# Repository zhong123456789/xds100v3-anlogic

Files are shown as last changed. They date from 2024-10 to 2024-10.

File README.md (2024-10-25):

#  **`Anlogic EF2M45 XDS100V3国产化方案`**

XDS100V3的FPGA部分仅用作JTAG协议转换功能，因此可选择使用国产FPGA；目前选择Anlogic方案，EF2M45，EF2M45封装为LQFP48，且包含内部Flash，无需外挂外部Flash存储FPGA bit文件，且仅需要单相供电，可降低layout难度；  
因为封装偏小，需要裁剪原有的部分引脚，屏蔽部分功能，当前已完成测试，实物如下：  

  

## 1.1、电路原理图

#### 电源部分
FPGA和FT2232仅需要1.8V、3.3V和VTAG  
* 3.3V电源电路，如下：     
  

* 1.8V电源，由FT2232 内部的LDO产生，后级VTAG仅需要1.8V作为参考，功耗不大   
  

* VTAG电源，根据JTAG TVD信号的电平，输出同步电压，给FPGA BANK0供电，实现与不同电平电路的互联
BANK0 手册要求供电电压>1.5V，建议D4使用低电压降的二极管，保证VTAG>1.5V  
  

FPGA个BANK电压，BANK1-3供电电压为3.3V，BANK0为VTAG 

#### FPGA部分 BANK0、BANK1
* BANK0:   
DTS JTAG的所有信号，FPGA的JTAG Pin和XDS100V3的JTAG Pin复用，通过EF_PROG_EN_n和EF_JTAGEN信号切换功能；
* BANK1：   
  串口信号;  
  50M时钟信号（原版位100M，当前修改为50M，通过内部的PL锁定至100M）;  
  POR_RST：复位信号；   
  PWERGOOD： TVD功能信号，当VTAG > 3V3/2时输出高电平，代表供电正常；    
  

  

#### FPGA部分 BANK2、BANK3
* BANK2  
ADV_MODE_LED：LED状态信号；  
Alt_Func_n  : FT2232输出的Alt功能控制信号；  
Dtsa_byp_n  : FT2232与FPGA间互联信号；  
CTL_DIS     : FT2232与FPGA间互联信号；  
* BANK3  
FT2232与FPGA间互联的大部分信号  

  

#### FT2232电路
FT2232电路电路如下：  
  

#### 注意
EF_JTAGEN建议使用<= 1K电阻下拉，否则会导致FPGA工作异常；  
  

## 1.2、FPGA VHDL文件综合
Anlogic EF2M45 使用Anlogic TangDynasty（简称TD）软件开发，因此我们需要使用TD软件重新综合VHDL文件；  

### 1.2.1、TD软件安装
[Anlogic官方TD下载链接](https://www.anlogic.com/support/tools-downloads)，官网下载需要升级到对应的权限，需要发邮件给Anlogic说明需求等待回复；建议下载仅包含Release的包，其他描述的可能不支持EF2M45器件  

  

安装完成后复制license到安装目录即可使用；  

### 1.2.2、创建工程、添加VHDL文件
* 创建工程  
选择EF2M45LG48B器件  
  

* FPGA的JTAG作为普通IO  
  

* 选择添加HDL文件  
  

* 移除dtsa_a3p060.vhd文件  
不需要dtsa_a3p060.vhd文件，移除即可  
  

* 设置xds-anlogic.vhdl为顶层文件  
该文件调用了dtsa_a3p125，配置dtsa_a3p125某些未使用的port为默认值  
  

### 1.2.3、添加PLL IP核

因为工程需要PLL将50M时钟信号锁频到100M，所以需要添加PLL IP核    
* 按照下图配置IP对应参数  
  

* 确认参数后点击生成VHDL文件  
  

  

* 刷新检查VHDL文件语法，确认语法正常  
  

### 1.2.4、添加引脚约束ADC文件
添加ADC引脚约束文件，分配配置FPGA引脚  
  

文件内容如下：  
```BASH
# bank 0 
set_pin_assignment	{ io_dts_keeper_pin }	{ LOCATION = P3 ; IOSTANDARD = LVCMOS33; PULLTYPE = NONE    ; SLEWRATE = SLOW; DRIVESTRENGTH = 4; }
set_pin_assignment	{ io_dts_nsrst_pin }	{ LOCATION = P6 ; IOSTANDARD = LVCMOS33; PULLTYPE = PULLUP  ; SLEWRATE = SLOW; DRIVESTRENGTH = 4; }
set_pin_assignment	{ o_dts_ntrst_pin }	    { LOCATION = P7 ; IOSTANDARD = LVCMOS33; PULLTYPE = NONE    ; SLEWRATE = SLOW; DRIVESTRENGTH = 4; }
set_pin_assignment	{ o_dts_emu3_pin }	    { LOCATION = P9 ; IOSTANDARD = LVCMOS33; PULLTYPE = PULLUP  ; SLEWRATE = SLOW; DRIVESTRENGTH = 4; }
set_pin_assignment	{ i_dts_emu2_pin }	    { LOCATION = P10; IOSTANDARD = LVCMOS33; PULLTYPE = PULLUP  ; }
set_pin_assignment	{ o_dts_tck_pin }	    { LOCATION = P11; IOSTANDARD = LVCMOS33; PULLTYPE = NONE    ; SLEWRATE = FAST; DRIVESTRENGTH = 4; }
set_pin_assignment	{ i_dts_tdo_pin }	    { LOCATION = P12; IOSTANDARD = LVCMOS33; PULLTYPE = PULLUP  ;}
set_pin_assignment	{ o_dts_tdi_pin }	    { LOCATION = P13; IOSTANDARD = LVCMOS33; PULLTYPE = NONE    ; SLEWRATE = FAST; DRIVESTRENGTH = 4; }
set_pin_assignment	{ io_dts_tmsc_pin }	    { LOCATION = P14; IOSTANDARD = LVCMOS33; PULLTYPE = NONE    ; SLEWRATE = FAST; DRIVESTRENGTH = 4; }

#bank 1
set_pin_assignment	{ i_dts_tvd_pin }	    { LOCATION = P19; IOSTANDARD = LVCMOS33; PULLTYPE = PULLDOWN; }
set_pin_assignment	{ i_por_n_pin }	        { LOCATION = P21; IOSTANDARD = LVCMOS33; PULLTYPE = NONE    ; }
set_pin_assignment	{ i_clk_50m }	        { LOCATION = P22; IOSTANDARD = LVCMOS33; PULLTYPE = NONE    ;  }
set_pin_assignment	{ o_rxd_out }	        { LOCATION = P24; IOSTANDARD = LVCMOS33; PULLTYPE = NONE    ; SLEWRATE = FAST; DRIVESTRENGTH = 20; }
set_pin_assignment	{ i_txd_in }	        { LOCATION = P25; IOSTANDARD = LVCMOS33; PULLTYPE = PULLUP  ; }
set_pin_assignment	{ o_pll_clk_out }	    { LOCATION = P16; IOSTANDARD = LVCMOS33; PULLTYPE = NONE    ; SLEWRATE = FAST; DRIVESTRENGTH = 20; }

#bank 2
set_pin_assignment	{ o_adv_mode_led }	    { LOCATION = P26; IOSTANDARD = LVCMOS33; PULLTYPE = NONE    ; SLEWRATE = SLOW; DRIVESTRENGTH = 4; }
set_pin_assignment	{ i_alt_function_n }	{ LOCATION = P27; IOSTANDARD = LVCMOS33; PULLTYPE = PULLUP  ; }
set_pin_assignment	{ i_dtsa_byp_n }	    { LOCATION = P28; IOSTANDARD = LVCMOS33; PULLTYPE = PULLUP  ; }
set_pin_assignment	{ o_ctlr_tdis_pin }	    { LOCATION = P30; IOSTANDARD = LVCMOS33; PULLTYPE = NONE    ; SLEWRATE = SLOW; DRIVESTRENGTH = 2; }

#bank 3
set_pin_assignment	{ i_ctlr_pod_rls_pin }	{ LOCATION = P34; IOSTANDARD = LVCMOS33; PULLTYPE = PULLUP  ; }
set_pin_assignment	{ i_ctlr_emu1_pin }	    { LOCATION = P36; IOSTANDARD = LVCMOS33; PULLTYPE = PULLUP  ; }
set_pin_assignment	{ o_ctlr_tvd_pin }	    { LOCATION = P37; IOSTANDARD = LVCMOS33; PULLTYPE = NONE    ; SLEWRATE = FAST; DRIVESTRENGTH = 20; }
set_pin_assignment	{ o_clk_fail_pin }	    { LOCATION = P38; IOSTANDARD = LVCMOS33; PULLTYPE = NONE    ; SLEWRATE = FAST; DRIVESTRENGTH = 20; }

set_pin_assignment	{ i_ctlr_nsrst_pin }	{ LOCATION = P39; IOSTANDARD = LVCMOS33; PULLTYPE = PULLUP  ; }
set_pin_assignment	{ o_ctlr_rtck_pin }	    { LOCATION = P40; IOSTANDARD = LVCMOS33; PULLTYPE = NONE    ; SLEWRATE = FAST; DRIVESTRENGTH = 20; }
set_pin_assignment	{ i_ctlr_emu0_pin }	    { LOCATION = P41; IOSTANDARD = LVCMOS33; PULLTYPE = PULLUP  ; }
set_pin_assignment	{ i_ctlr_emu_en_pin }	{ LOCATION = P42; IOSTANDARD = LVCMOS33; PULLTYPE = PULLUP  ; }

set_pin_assignment	{ i_ctlr_ntrst_pin }	{ LOCATION = P43; IOSTANDARD = LVCMOS33; PULLTYPE = PULLUP  ; }

set_pin_assignment	{ i_ctlr_tms_pin }	    { LOCATION = P44; IOSTANDARD = LVCMOS33; PULLTYPE = PULLUP  ; }
set_pin_assignment	{ o_tdo_to_ctlr }	    { LOCATION = P45; IOSTANDARD = LVCMOS33; PULLTYPE = NONE    ; SLEWRATE = FAST; DRIVESTRENGTH = 20; }
set_pin_assignment	{ i_ctlr_tdi_pin }	    { LOCATION = P46; IOSTANDARD = LVCMOS33; PULLTYPE = PULLUP  ; }
set_pin_assignment	{ i_ctlr_tck_pin }	    { LOCATION = P47; IOSTANDARD = LVCMOS33; PULLTYPE = PULLUP  ; }
```
### 1.2.5、添加时序约束SDC文件
参考3.2.4、添加引脚约束ADC文件，SDC文件内容如下  
```BASH
# create_clock -add -name <string> -period <double> -waveform <string> target
# new input clock is 50 Mhz
create_clock  -period 20 -waveform {0 10} [get_ports i_clk_50m]
create_clock  -period 10 -waveform {0 5} [get_nets {pll_clk_u0/clkc_wire[0]}]

# fastest TCK can be is master_clk/2
create_generated_clock -name {internal_tck} -divide_by 2 -source [get_nets {pll_clk_u0/clkc_wire[0]}] [get_nets {dtsa_fpga/DTSK/TC0/tsm_pres_st[3]}]

#------------------------------------------------------
# False Path Constraints to test points and LEDs
#------------------------------------------------------

set_false_path -to [get_ports { o_adv_mode_led}]

#------------------------------------------------------
# False path to/from points with no real timing
#------------------------------------------------------

set_false_path -from [get_ports {io_dts_nsrst_pin}] -to [get_ports {o_clk_fail_pin}]
set_false_path -from [get_ports {i_ctlr_nsrst_pin}] -to [get_ports {io_dts_nsrst_pin} ]

set_false_path  -to [get_ports {o_ctlr_tvd_pin}]
set_false_path  -to [get_ports {o_ctlr_tdis_pin}]
set_false_path  -to [get_ports {o_clk_fail_pin}]

set_false_path -from [get_ports {i_ctlr_pod_rls_pin}] 
set_false_path -from [get_ports {i_dtsa_byp_n}] 
set_false_path -from [get_ports {i_ctlr_emu_en_pin}] 
set_false_path -from [get_ports {i_alt_function_n}]

set_false_path -from [get_ports {i_txd_in}]
set_false_path -to [get_ports {o_rxd_out}]

set_false_path -from [get_ports {i_dts_emu2_pin}]
set_false_path -to [get_ports {o_dts_emu3_pin}]
#------------------------------------------------------
# Maximum Delay Constraints
#------------------------------------------------------

set_max_delay 25.00 -from [get_ports {i_ctlr_ntrst_pin}] -to [get_ports {o_dts_ntrst_pin}]
```

### 1.2.6、综合VHDL文件
点击RUN按钮一键综合 HDL文件，可下方查看生产结构及资源消耗情况


### 1.2.7、烧录到FPGA FLASH
* 点击Download按钮,如果显示No hardware，可能是Anlogic USA JTAG下载器的驱动未安装需要手动安装，驱动目录位于 `软件安装目录/driver` 目录下  

* 安装完成驱动后，设备管理器，应该有`AL-Link` 设备  


* 将EF_JTAGEN信号拉高即可刷新出EF2M45B设备  


* 烧录到FPGA FLASH  



### 注意： ###   
因为FPGA的JTAG复用作为IO，但是与PCB上的丝印的映射不同，烧录下载时需要按下图连接下载器：  


## 1.3、FT2232 EEPROM设置
使用FTDI的官方软件[FT_Prog](https://ftdichip.com/utilities/)编辑配置FT2232，打开软件点击 `DEVICES` -> `Scan and Parse`，软件会自动扫描连接设备，按以下配置各参数：
* USB Device Descriptors:  


* USB Config Descriptors:  


* USB String Descriptors:  


* PortA Hardware Specific  


* PortA Driver  


* PortB Hardware Specific  


* PortB  Driver  


修改完成后点击 `DEVICES` -> `Program`烧录配置到FT2232外挂的EEPROM中，然后再点击软件`DEVICES` -> `Scan and Parse`刷新读取FT2232外挂的EEPROM信息：
* EEPROM信息如下


## 1.4、功能测试
使用TI 的CCS IDE测试XDS100V3，结果如下：   


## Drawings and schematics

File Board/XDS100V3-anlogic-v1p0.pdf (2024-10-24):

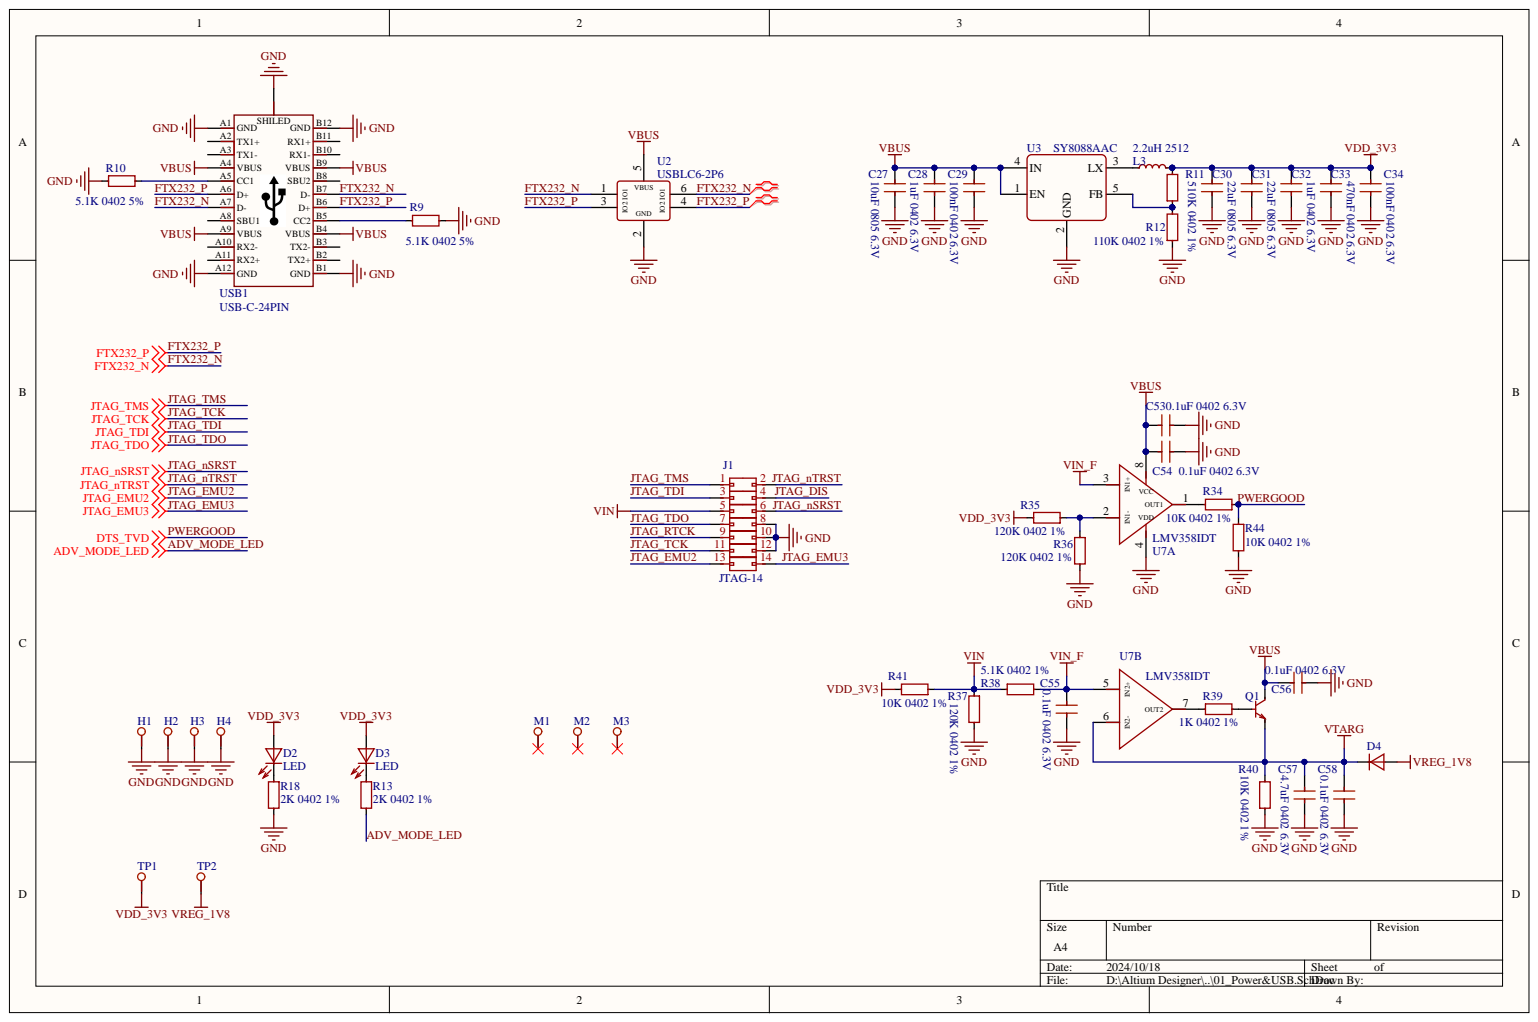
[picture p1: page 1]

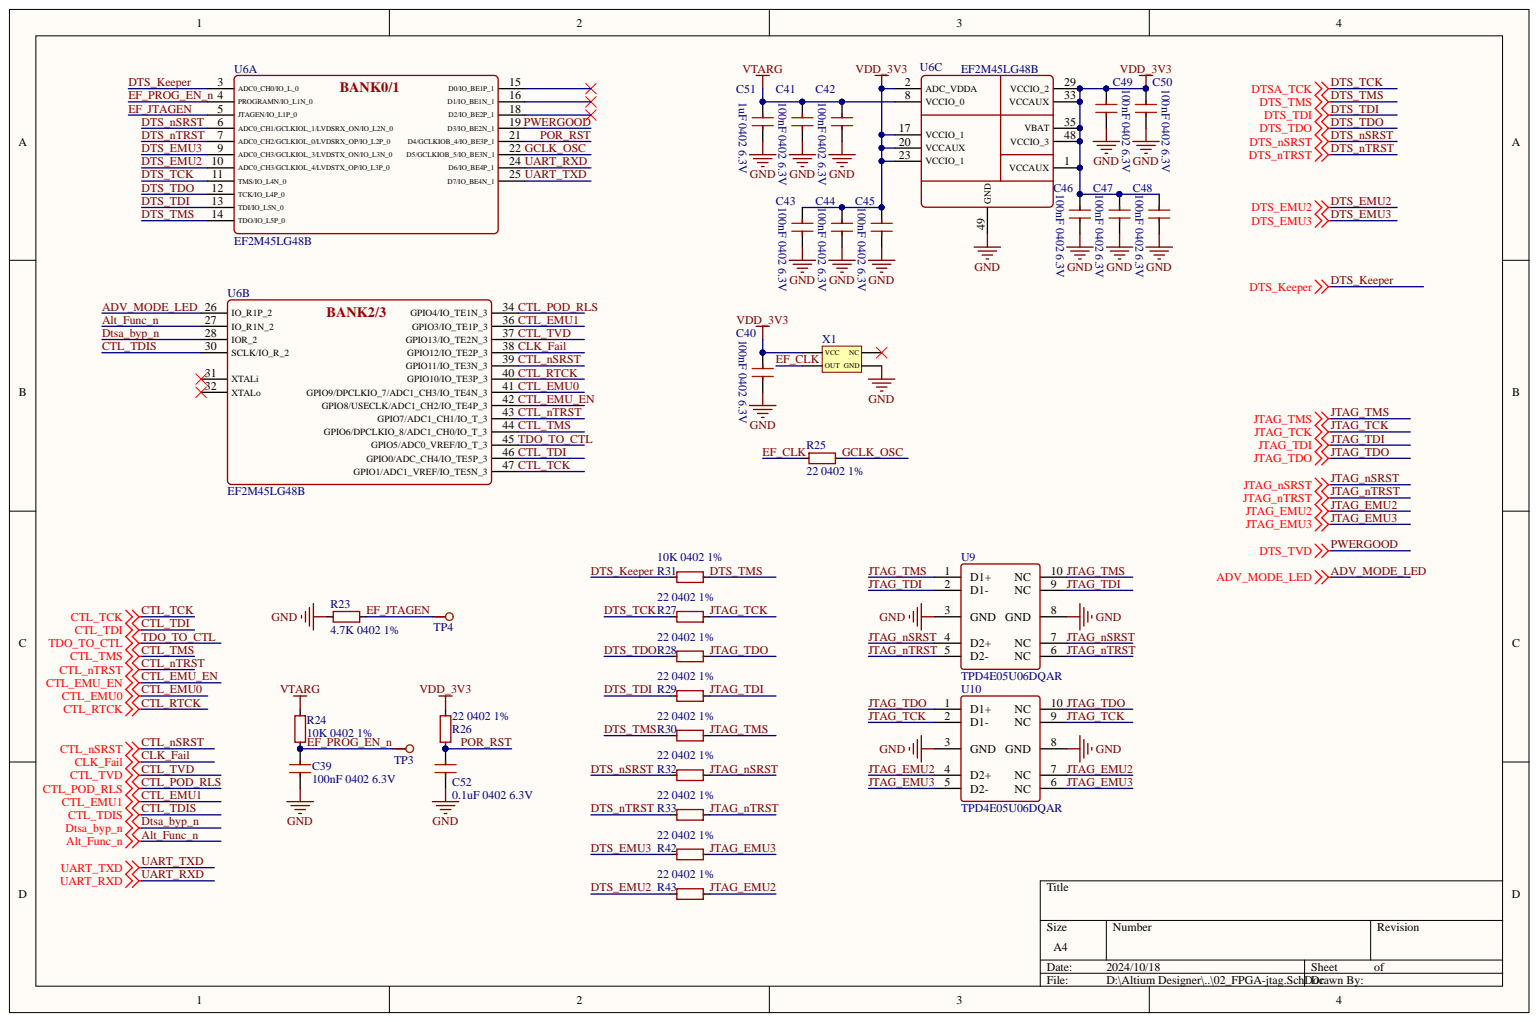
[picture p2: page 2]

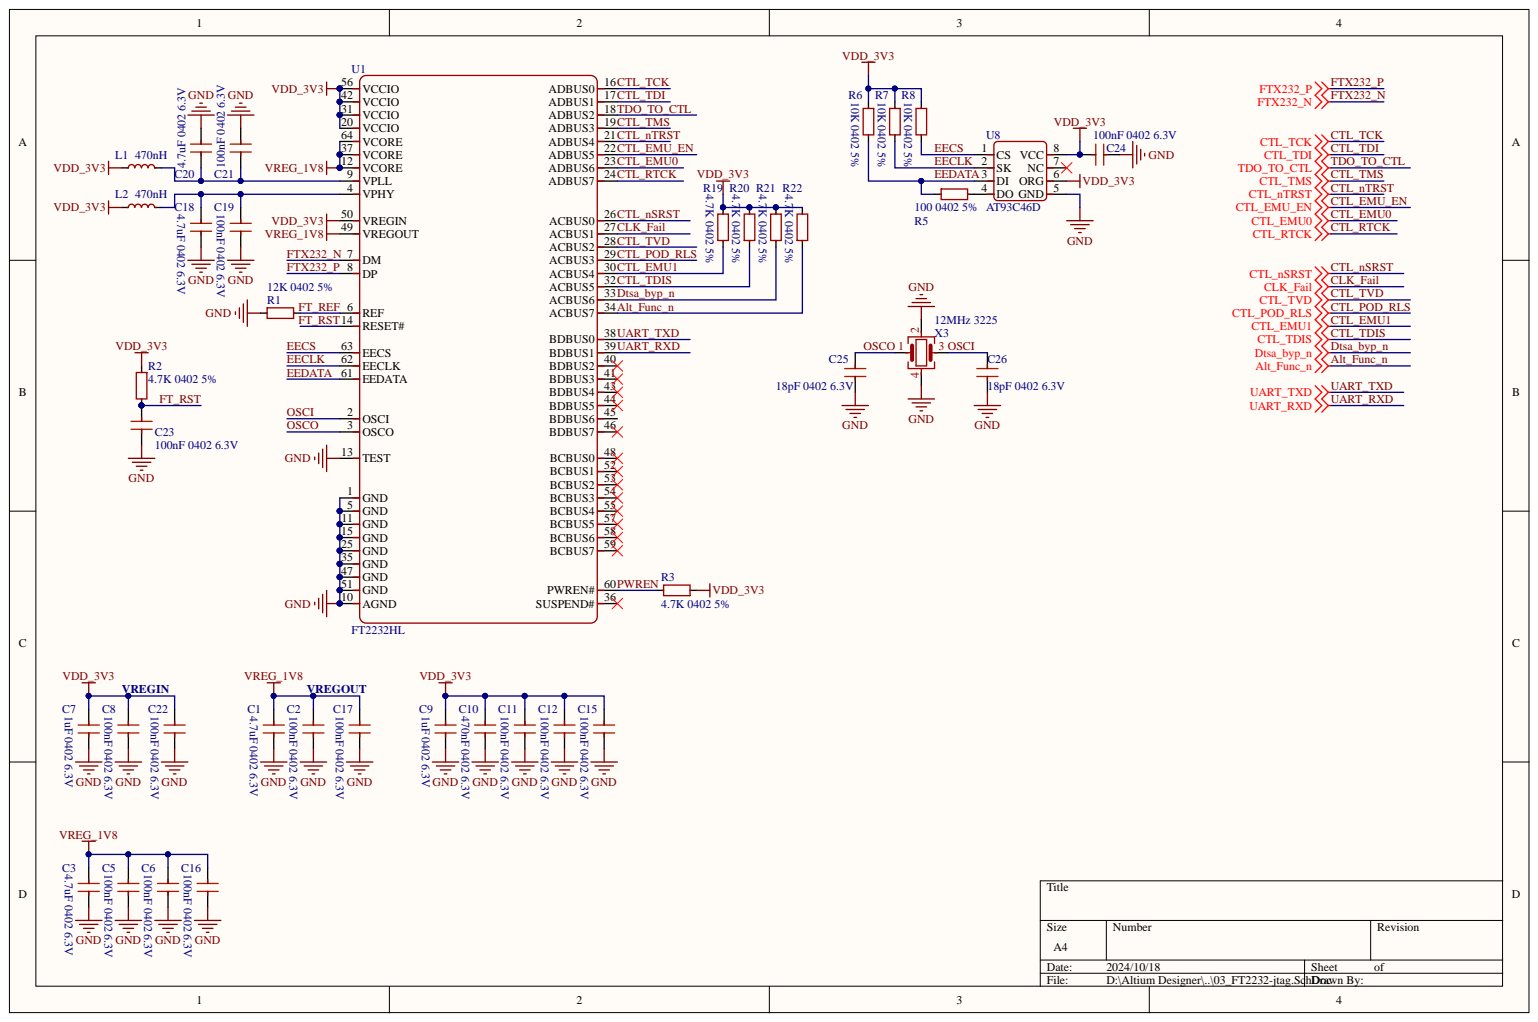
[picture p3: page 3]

VPHY 4 VPLL 9 VCORE 12 VCORE 37 VCORE 64 VCCIO 20 VCCIO 31 VCCIO 42 VCCIO 56

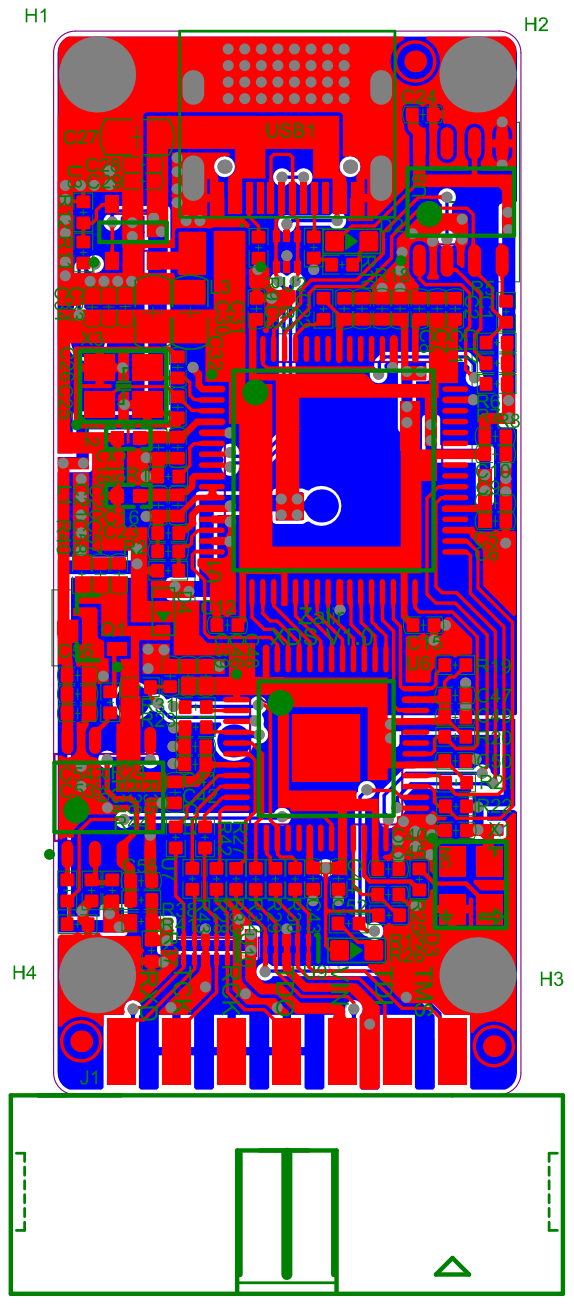
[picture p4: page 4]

Comment | Description | Designator | Footprint | LibRef | Quantity
4.7uF 0402 6.3V | Unpolarized capacitor | C1, C3, C18, C21, C57C_0402_1005Metric | C | 5
100nF 0402 6.3V | Unpolarized capacitor | C2, C5, C6, C8, C11, CC_0 402_ 1005 Metric | C | 28
1uF 0402 6.3V | Unpolarized capacitor | C7, C9, C28, C32, C51C_0402_1005Metric | C | 5
470nF 0402 6.3V | Unpolarized capacitor | C10,C33 | C_0402_1005Metric | C | 2
18pF 0402 6.3V | Unpolarized capacitor | C25,C26 | C_0402_1005Metric | C | 2
10uF 0805 6.3V | Unpolarized capacitor | C27 | C_0805_2012Metric | C | 1
22uF 0805 6.3V | Unpolarized capacitor | C30,C31 | C_0805_2012Metric | C | 2
0.1uF 0402 6.3V | Unpolarized capacitor | C52, C53, C54, C55, CC_0 402_1005Metric | C | 6
LED | Light emitting diode | D2, D3 | LED_0603_1608MetricLED | 2
Diode | Diode_AK | D4 | SOD-523F_0P9X1P3_Diode | 1
TestPoint | test point tp | H1, H2, H3, H4 | M2-HOLE | TestPoint | 4
JTAG-14 | Generic connector, sinJ1 | DC3_14P_2.54MM_V | Generic_Conn_02x07 | 1
470nH | Inductor | L1, L2 | L0402-SMD | L | 2
2.2uH 2512 | Inductor | L3 | L_252012-TEMP | L | 1
TestPoint | test point tp | M1, M2, M3 | Mark-1mm | TestPoint | 3
NPN-BEC | NPN transistor, base/cQ1 | NPN-BCE | NPN-BEC | 1
12K 0402 5% | Resistor | R1 | R_0402_1005Metric | R | 1
4.7K 0402 5% | Resistor | R2, R3, R19, R20, R21R_0402_1005Metric | R | 6
100 0402 5% | Resistor | R5 | R_0402_1005Metric | R | 1
10K 0402 5% | Resistor | R6, R7, R8 | R_0402_1005Metric | R | 3
5.1K 0402 5% | Resistor | R9, R10 | R_0402_1005Metric | R | 2
510K 0402 1% | Resistor | R11 | R_0402_1005Metric | R | 1
110K 0402 1% | Resistor | R12 | R_0402_1005Metric | R | 1
2K 0402 1% | Resistor | R13, R18 | R_0402_1005Metric | R | 2
4.7K 0402 1% | Resistor | R23 | R_0402_1005Metric | R | 1
10K 0402 1% | Resistor | R24, R31, R34, R40, RR_0402_1005Metric | R | 6
22 0402 1% | Resistor | R25, R26, R27, R28, RR_0402_1005Metric | R | 10
120K 0402 1% | Resistor | R35, R36, R37 | R_0402_1005Metric | R | 3
5.1K 0402 1% | Resistor | R38 | R_0402_1005Metric | R | 1
1K 0402 1% | Resistor | R39 | R_0402_1005Metric | R | 1
TestPoint | test point tp | TP1, TP2, TP3, TP4 | TP-60MIL | TestPoint | 4
FT2232HL | FT2232H Dual High SpU1 | FT2232HL-LQF P-64-HFT2232HL | 1
USBLC6-2P6 | Low Capacitance 2-LinU2 | USBLC6-2P6-SOT-563USBLC6-2P6 | 1
SY8088AAC | High Efficiency | U3 | SY8088AAC | SY8088AAC | 1
EF2M45LG48B | SALELF® 2 系列 FPGAU6 | EF2M45_LQFP-48L | EF2M45LG48B | 1
LMV358IDT | Low cost, low power, iU7 | LMV358IDT-SOP8 | LMV358IDT | 1
AT93C46D | Three-Wire AutomotivU8 | AT93C46DN | AT93C46D | 1

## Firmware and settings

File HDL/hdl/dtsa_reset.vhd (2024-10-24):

-- TI Proprietary Information - Internal Data.  Copyright (c) 2011, Texas Instruments Incorporated.  All rights reserved.
library ieee; use ieee.std_logic_1164.all; use ieee.std_logic_arith.all; use ieee.std_logic_unsigned.all; library work; use work.dtsa_cj_pkg.all; entity E42e is port(por_n:in std_logic; master_clk:in std_logic; itck:in std_logic; ctlr_ntrst_pin:in std_logic; 
ctlr_tms_pin:in std_logic; ctlr_tdi_pin:in std_logic; loop_around:in std_logic; por_n_sync:out std_logic; reset_n:out std_logic; reset_n_fe:out std_logic; trst_na:out std_logic; trst_sync:out std_logic ); end E42e; architecture RTL of E42e is 
signal S1:std_logic; signal S2:std_logic; signal S3:std_logic_vector(1 downto 0); signal S4:std_logic; signal S5:std_logic; signal S6:std_logic; signal S7:std_logic; signal S8:std_logic; signal S9:std_logic; signal S10:std_logic; signal S11:std_logic; 
signal S12:std_logic; signal S13:std_logic; signal S14:std_logic; signal S15:std_logic; signal S16:std_logic; signal S17:std_logic; signal S18:std_logic; begin I47:process(por_n,master_clk) begin if(por_n='0')then 
por_n_sync<='0'; elsif(master_clk'event and master_clk='1')then por_n_sync<='1'; end if; end process I47; I48:process(por_n,master_clk) begin if(por_n='0')then S14<='0'; S15<='0'; S16<='0'; 
elsif(master_clk'event and master_clk='1')then S14<=ctlr_ntrst_pin; S15<=S14; S16<=S15; end if; end process I48; S13<=S16 AND not S15; I49:process(por_n,master_clk) begin if(por_n='0')then S10<='0'; 
S11<='0'; S12<='0'; elsif(master_clk'event and master_clk='1')then S10<=ctlr_tms_pin; S11<=S10; S12<=S11; end if; end process I49; S9<=S12 XOR S11; I50:process(por_n,master_clk) begin 
if(por_n='0')then S3<=(others=>'0'); elsif(master_clk'event and master_clk='1')then if(S9='1')OR(S6='0')then S3<=(others=>'0'); elsif(S13='1')then S3<=S3+"01"; end if; end if; end process I50; S7<='1'when S3="11"else'0'; 
S1<=not S15 when loop_around='1'else (S7 AND S6); I51:process(por_n,master_clk) begin if(por_n='0')then S4<='0'; elsif(master_clk'event and master_clk='1')then S4<=S1; end if; end process I51; I52:process(por_n,master_clk) 
begin if(por_n='0')then S8<='0'; elsif(master_clk'event and master_clk='1')then S8<=ctlr_tdi_pin; end if; end process I52; I53:process(por_n,master_clk) begin if(por_n='0')then S2<='0'; 
elsif(master_clk'event and master_clk='1')then S2<=not(S14 OR S10 OR S8); end if; end process I53; I54:process(por_n,master_clk) begin if(por_n='0')then S5<='0'; S6<='0'; elsif(master_clk'event and master_clk='1')then S5<=not(S2 OR S4); 
S6<=S5; end if; end process I54; reset_n<=S6; I55:process(por_n,master_clk) begin if(por_n='0')then reset_n_fe<='0'; elsif(master_clk'event and master_clk='0')then reset_n_fe<=S5; end if; 
end process I55; trst_na<=ctlr_ntrst_pin AND por_n; I56:process(ctlr_ntrst_pin,por_n,itck) begin if(ctlr_ntrst_pin AND por_n)='0'then S17<='0'; S18<='0'; elsif(itck'event and itck='0')then S17<='1'; S18<=S17; end if; 
end process I56; trst_sync<=S18; end RTL; 
